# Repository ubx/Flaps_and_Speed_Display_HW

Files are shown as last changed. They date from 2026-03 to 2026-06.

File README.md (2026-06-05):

# Flaps & Speed

A KiCad project for a hardware module designed to interface with flap and speed sensors, likely for aviation or automotive applications.

## Features
- **CAN Bus Communication:** Includes CAN-In and CAN-Out interfaces using the SN65HVD230 transceiver.
- **Connectors:** Utilizes M12 5-pin connectors for reliable external connections.
- **Power:** Designed for 12V input with onboard 3.3V regulation, [Micro BEC SE-0509](https://de.aliexpress.com/item/1005010499841098.html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)
- **Display:** Connected (H7-H14) to a [ESP32-S3-Touch-AMOLED-1.75](https://de.aliexpress.com/item/1005008989323572.html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), [Wiki](https://www.waveshare.com/wiki/ESP32-S3-Touch-AMOLED-1.75)

## Software

This hardware module is designed to run the following software:
[Flaps and Speed Display](https://github.com/ubx/Flaps_and_Speed_Display)

## Todo
- [x] Review PCB toward a more professional layout
- [x] Crate a PCBWay ready BOM
- [ ] Add more professional displays connector
- [ ] Test kicad-happy ???

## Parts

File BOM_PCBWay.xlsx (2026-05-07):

 |  |  | T-M12W940229A PCS BOM
Item # | *Designator | *Qty | Manufacturer | *Mfg Part # | Description / Value | *Package/Footprint | Type | Your Instructions / Notes
1 | U1 | 1 | Texas Instruments | SN65HVD230DR | SN65HVD230 (CAN Bus Transceivers, 3.3V, 1Mbps, Low-Power capabilities, SOIC-8) | Package_SO:SOIC-8_3.9x4.9mm_P1.27mm | smd | Assembly: Yes
2 | R2 | 1 | Yageo | RC1206FR-07120RL | 120 (Resistor) | Resistor_SMD:R_1206_3216Metric_Pad1.30x1.75mm_HandSolder | smd | Assembly: Yes
3 | R1 | 1 | Yageo | RC1206FR-0710KL | 10K (Resistor) | Resistor_SMD:R_1206_3216Metric_Pad1.30x1.75mm_HandSolder | smd | Assembly: Yes
4 | L1 | 1 | TDK | ACT1210-220-2P-TL00 | ACT1210-220-2P-TL00 (Signal Line Common Mode Chokes/Filters) | ACT1210_TDK | smd | Assembly: Yes
5 | C3 | 1 | Murata | GRM31C5C1H101JA01L | 100pF (Unpolarized capacitor) | Resistor_SMD:R_1206_3216Metric_Pad1.30x1.75mm_HandSolder | smd | Assembly: Yes
6 | C2 | 1 | Murata | GRM31C5C1H101JA01L | 100pF (Unpolarized capacitor) | Resistor_SMD:R_1206_3216Metric_Pad1.30x1.75mm_HandSolder | smd | Assembly: Yes
7 | C1 | 1 | Murata | GRM31MR71H104KA01L | 100nF (Unpolarized capacitor) | Resistor_SMD:R_1206_3216Metric_Pad1.30x1.75mm_HandSolder | smd | Assembly: Yes

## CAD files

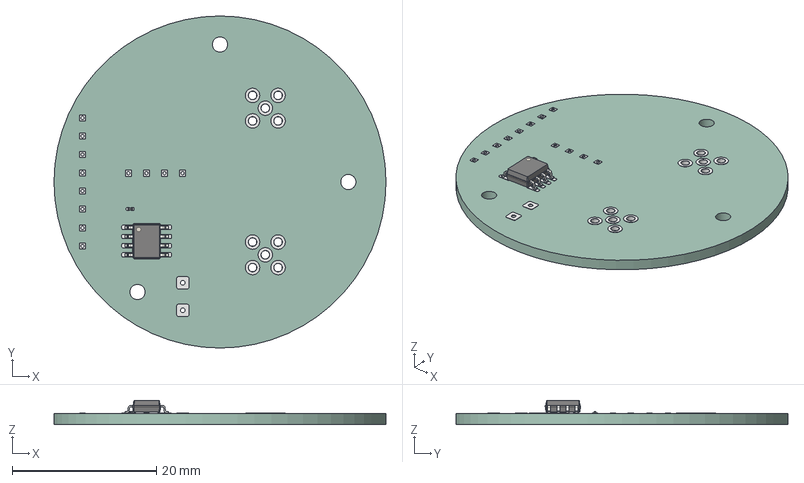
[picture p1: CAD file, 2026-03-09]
Flaps&Speed.step
46.0 x 46.0 x 3.38 mm
SOIC-8_3.9x4.9mm_P1.27mm
R_0201_0603Metric
Flaps&Spedd_pad
Flaps&Spedd_PCB

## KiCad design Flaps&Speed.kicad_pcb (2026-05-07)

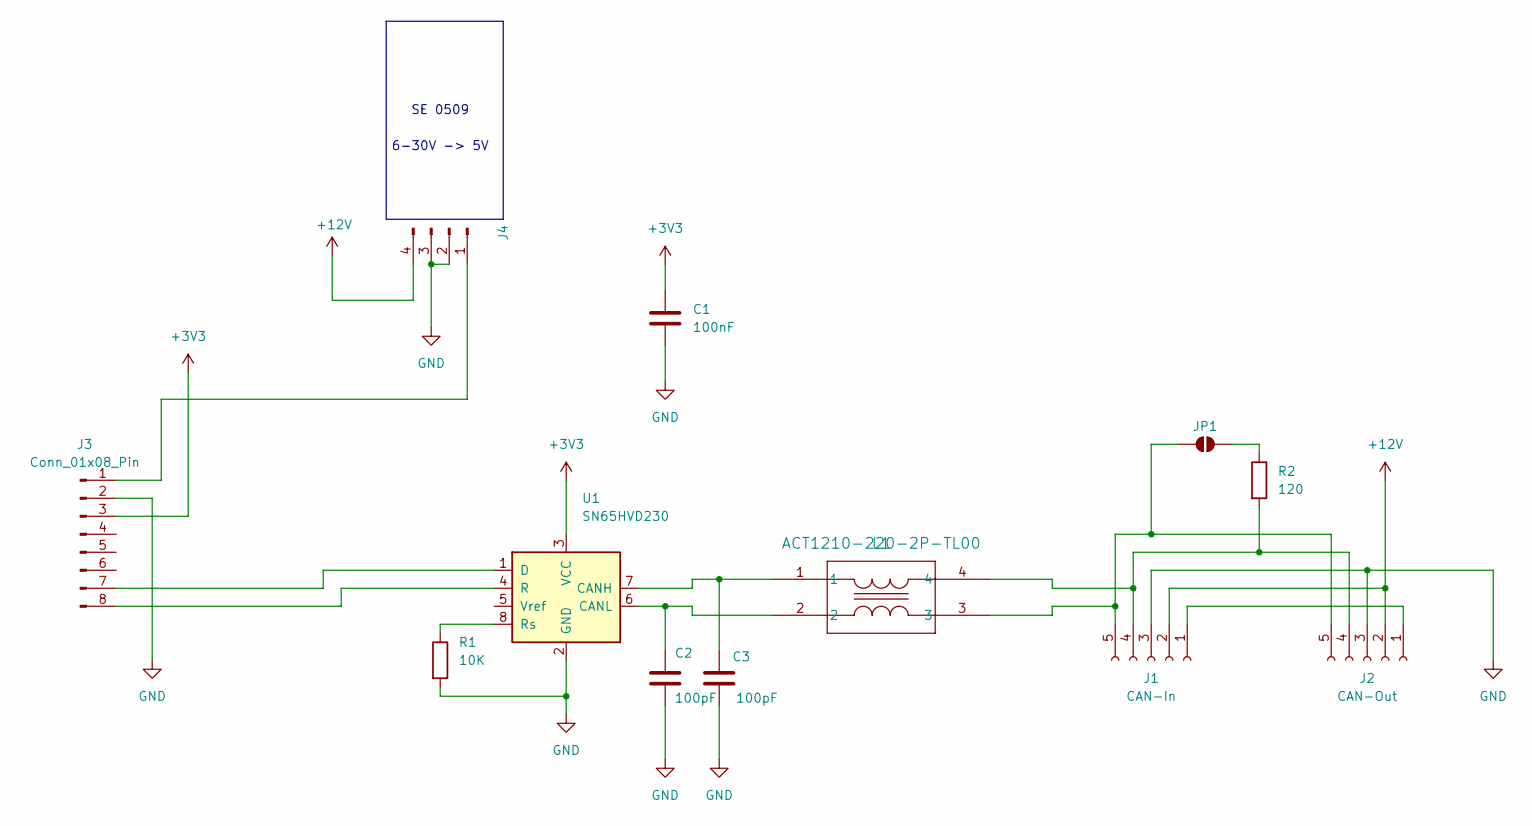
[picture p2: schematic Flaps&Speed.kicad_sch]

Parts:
C1: 100nF; R_1206_3216Metric_Pad1.30x1.75mm_HandSolder; MPN GRM31CR71H104KA01L
C2, C3: 100pF; R_1206_3216Metric_Pad1.30x1.75mm_HandSolder; MPN GRM31C5C1H101JA01L
J1: CAN-In; M12_A_5pin_Male_PCD5_Drill1p2
J2: CAN-Out; M12_A_5pin_Male_PCD5_Drill1p2
J3: Conn_01x08_Pin; PinSocket_1x08_P2.54mm_Vertical
J4: Conn_01x04_Pin; PinSocket_1x04_P2.54mm_Vertical
JP1: SolderJumper_2_Open; SolderJumper-2_P1.3mm_Open_TrianglePad1.0x1.5mm
L1: ACT1210-220-2P-TL00; ACT1210_TDK; MPN ACT1210-220-2P-TL00
R1: 10K; R_1206_3216Metric_Pad1.30x1.75mm_HandSolder; MPN RC1206FR-0710KL
R2: 120; R_1206_3216Metric_Pad1.30x1.75mm_HandSolder; MPN RC1206FR-07120RL
U1: SN65HVD230; SOIC-8_3.9x4.9mm_P1.27mm; MPN SN65HVD230DR

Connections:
+3V3: C1.1, J3.3, U1.3 (VCC)
+12V: J1.2, J2.2, J4.4
GND: C1.2, C2.2, C3.2, J1.3, J2.3, J3.2, J4.2, J4.3, R1.2, U1.2 (GND)
unnamed: J1.1, J2.1
unnamed: J1.4, J2.4, L1.4, R2.2
unnamed: J1.5, J2.5, JP1.1 (A), L1.3
unnamed: J3.1, J4.1
unnamed: J3.7, U1.1 (D)
unnamed: J3.8, U1.4 (R)
unnamed: JP1.2 (B), R2.1
unnamed: C3.1, L1.1, U1.7 (CANH)
unnamed: C2.1, L1.2, U1.6 (CANL)
unnamed: R1.1, U1.8 (Rs)

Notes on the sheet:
SE 0509
6-30V -> 5V

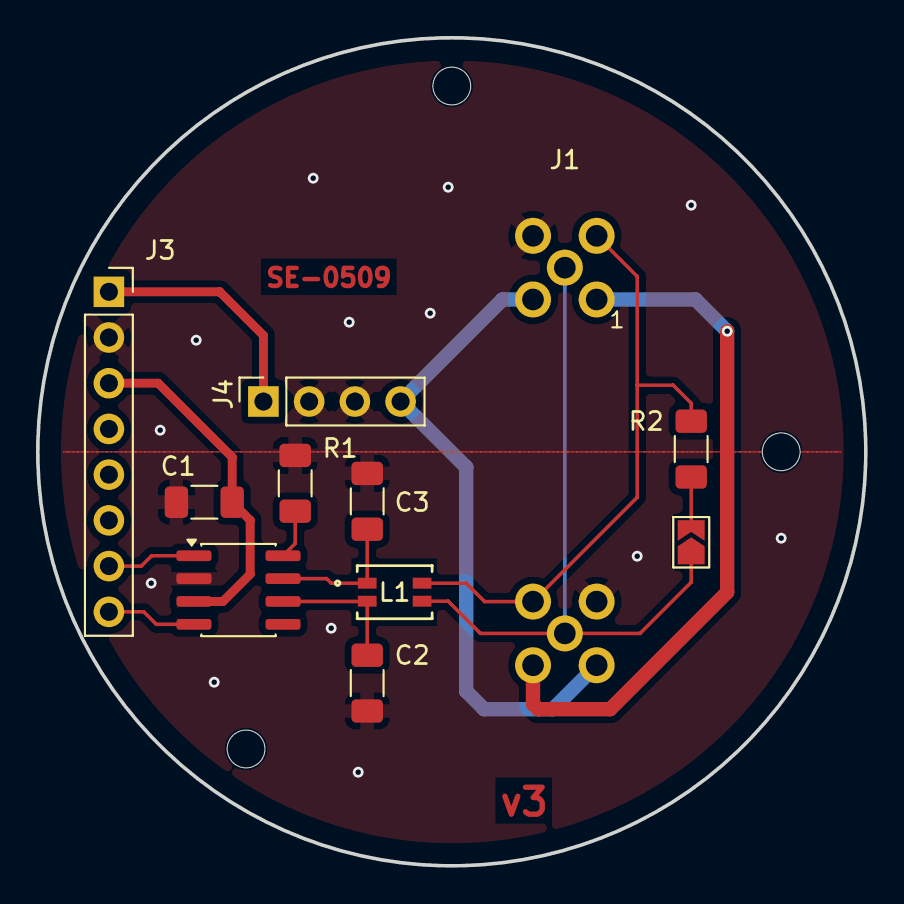
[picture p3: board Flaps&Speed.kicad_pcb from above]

Board: 2 copper layers, 46.0 x 46.0 mm, 15 parts (1 on the bottom side), 13 nets.

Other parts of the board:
MH1, MH2, MH3: MountingHole_2.1mm

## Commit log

2026-03-06 Label moved.
    [Flaps&Spedd.kicad_pcb]
2026-03-09 Change to PinHeader_1x01_P1.27mm_Vertical, add C1.
    [Flaps&Spedd.kicad_pcb, Flaps&Spedd.kicad_sch]
2026-03-11 Wrong CAN connector placement, mirrored!
    [Flaps&Spedd.kicad_pcb, Flaps&Spedd.kicad_sch]
2026-04-13 Add comment.
    [Flaps&Spedd.kicad_pcb]
2026-04-14 Update to KiCad 10.0
    [Flaps&Spedd.kicad_pcb]
2026-04-14 Fix: - Löcher Kontakte zu klein - DC Wandler Vin (12V) und Vout (5V) vertauscht - DC Wandler mehr zu Mitte - Widerstände und Kondensator anders Format
    [Flaps&Spedd.kicad_pcb]
2026-04-15 Remove unused track on F.Cu layer.
    [Flaps&Spedd.kicad_pcb]
2026-04-19 Update README: add Waveshare Wiki link for ESP32-S3-Touch-AMOLED-1.75 display
2026-04-22 Add GitHub Actions workflow for KiCad design reviews
2026-04-22 Enable manual trigger for KiCad design review workflow
2026-04-22 Update KiCad review workflow: switch to fork for power rail fix
2026-04-23 Revert "Update KiCad review workflow: switch to fork for power rail fix"
    This reverts commit bd045310696c16846bc347357ebf91971971c967.
    Due to the fix in commit 8bdef04633a99cd4ed570945c9695ed741ce7798.
2026-04-26 Add initial KiCad project files for "Flaps&Spedd" schematic and PCB
2026-05-03 Reapply "Update KiCad review workflow: switch to fork for power rail fix"
    This reverts commit c969e05315677aa3a7d3b74d35de44598b77a24d.
2026-05-04 Fix typo in project file names: rename "Flaps&Spedd" to "Flaps&Speed" across all KiCad files.
    [Flaps&Speed.kicad_pcb, Flaps&Speed.kicad_sch, Flaps&Speed.step]
2026-05-04 Adjust BOM settings and properties in KiCad project: updated field orders, added new properties, and fixed naming errors (e.g., "Flaps&Spedd" to "Flaps&Speed").
    [Flaps&Speed.kicad_pcb, Flaps&Speed.kicad_sch]
2026-05-07 Add LCSC properties to components and exclude specific through-hole parts from BOM
    [BOM_PCBWay.xlsx, Flaps&Speed.kicad_pcb]
2026-06-05 README: Mark PCB review as complete in todo list.
